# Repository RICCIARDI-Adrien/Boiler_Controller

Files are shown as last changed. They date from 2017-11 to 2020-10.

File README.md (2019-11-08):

# Boiler Controller

## Hardware
Schematics have been drawn using Eagle 8.3.1.  

### Power board
This board contains the AC/DC converter, the relays and the connector to the wall housing.
  
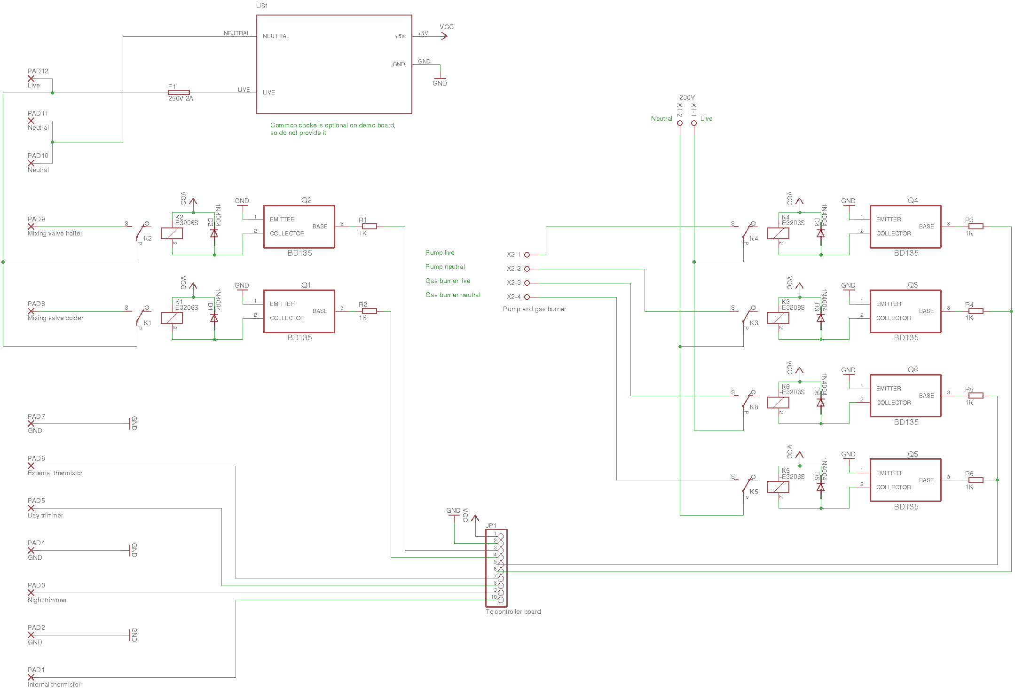
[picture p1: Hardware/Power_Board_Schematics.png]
Power board schematics

  
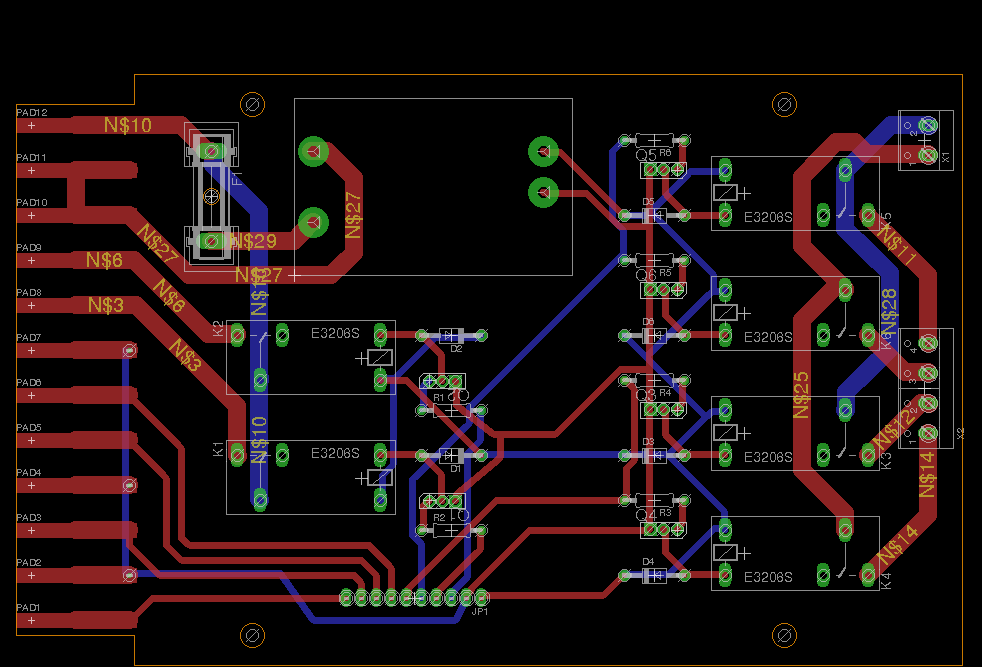
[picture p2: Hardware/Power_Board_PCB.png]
Power board PCB


### Controller board
This board holds the microcontroller and the WiFi to UART bridge.
  
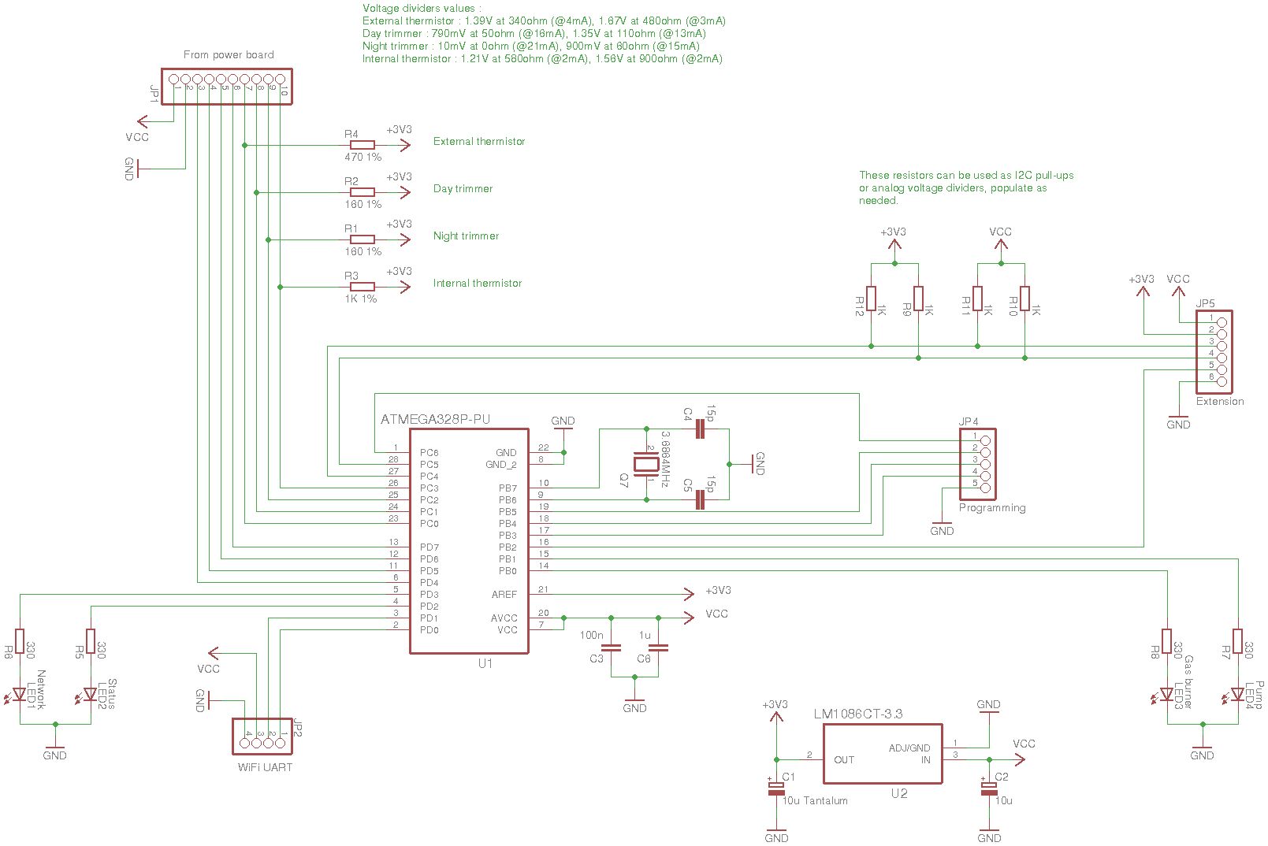
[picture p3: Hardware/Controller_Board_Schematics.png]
Controller board schematics


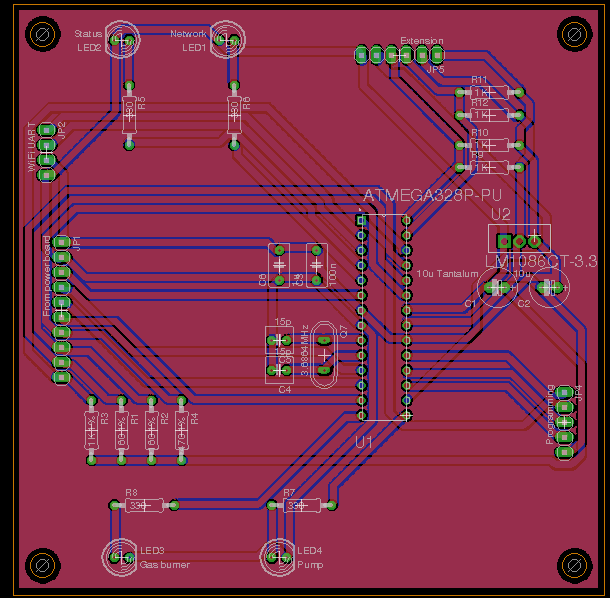
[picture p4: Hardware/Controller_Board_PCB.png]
Controller board PCB


### Components
* [Single pole 16A relay with 5V coil](http://fr.farnell.com/oeg-te-connectivity/omih-ss-105lm-300/relais-spst-no-250vac-30vdc-16a/dp/1891727)
* [BD135 NPN bipolar transistor](http://fr.farnell.com/stmicroelectronics/bd135/transistor-npn-to-126/dp/9801529)
* [1N4007 rectifier diode](http://fr.farnell.com/multicomp/1n4007/diode-1a-1000v/dp/9565051)
* [15pF ceramic capacitor](http://fr.farnell.com/multicomp/mc0805n150j101a2-54mm/condensateur-mlcc-c0g-np0-15pf/dp/2112750)
* [100nF ceramic capacitor](http://fr.farnell.com/multicomp/mc0805b104k500a5-08mm/condensateur-mlcc-0-1uf-50v-x7r/dp/2395773)
* [10uF electrolytic capacitor](http://fr.farnell.com/multicomp/mcgpr16v106m5x11/condensateur-elec-alu-10uf-16v/dp/9451056)
* [10uF tantalum capacitor](http://fr.farnell.com/multicomp/mctar16v106kc/condensateur-tantale-10uf-16v/dp/2395815)
* [5V 2A AC/DC power supply](http://fr.farnell.com/vigortronix/vtx-214-010-205/alimentation-ac-dc-5v-2a/dp/2464685)
* [160ohm 1% resistor](http://fr.farnell.com/multicomp/mf12-160r/resistance-0-125w-1-160r/dp/9342672)
* [330ohm 5% resistor](http://fr.farnell.com/multicomp/mcf-0-25w-330r/resistance-couche-carbon-330r/dp/9339418)
* [470ohm 1% resistor](http://fr.farnell.com/multicomp/mf50-470r/resistance-0-5w-1-470r/dp/9340610)
* [1Kohm 5% resistor](http://fr.farnell.com/multicomp/mcf-0-25w-1k/resistance-couche-carbon-1k-0/dp/9339051)
* [1Kohm 1% resistor](http://fr.farnell.com/multicomp/mf50-1k/resistance-1k-0-5w-1/dp/9339779)
* [Fuseholder](http://fr.farnell.com/littelfuse/64900001039/porte-fusible-cms-20x5mm/dp/1271673)
* [Fuse](http://fr.farnell.com/littelfuse/0232002-mxp/fuse-cartridge-medium-acting-2a/dp/1707348)
* [2-pad terminal](http://fr.farnell.com/camdenboss/ctb0708-2/bornier-standard-2-voies-30-12awg/dp/2315273)
* [4-pad terminal](http://fr.farnell.com/camdenboss/ctb0708-4/bornier-standard-4-voies-30-12awg/dp/2315275)
* [Atmega328p microcontroller](http://fr.farnell.com/microchip/atmega328p-pu/micro-8-bits-avr-32k-flash-28pdip/dp/1715487)
* [3.6864MHz crystal](http://fr.farnell.com/iqd-frequency-products/lfxtal003263/quartz-3-686400mhz/dp/9712909)
* [3.3V LDO](http://fr.farnell.com/texas-instruments/lm1086ct-3-3-nopb/ic-reg-ldo-3-3v-1-5a-to-220/dp/1564628)
* [WiFi to UART bridge](https://www.gotronic.fr/art-module-wifi-uart-grove-113020010-23827.htm)
* [4-pin PCB male connector](https://www.gotronic.fr/art-connecteur-s004-5858.htm)
* [4-pin PCB female connector](https://www.gotronic.fr/art-connecteur-p004-5867.htm)
* [10-pin PCB male connector](https://www.gotronic.fr/art-connecteur-s010-15367.htm)
* [10-pin PCB female connector](https://www.gotronic.fr/art-connecteur-p010-15370.htm)

### Analog signals characteristics
* Day trimmer : resistance variation from 50 to 110ohm.
* Night trimmer : resistance variation from 0 to 60ohm.
* Radiator water start thermistor : resistance variation from 580 (+80°C) to 900ohm (-20°C).
* Outside thermistor : resistance variation from 340 (+40°C) to 480ohm (-10°C).
  
Microcontroller uses a 3.3V precision voltage reference for the ADC module to gain more precision with small variation signals. All voltage dividers must be calculated as the highest variable resistance value results in a 3.3V maximum voltage on the ADC pin.

### Fuse value calculation
AC/DC converter inrush current is 40A for less than 500us, so a temporized fuse is needed to allow the board to boot.  
AC/DC converter maximum input current is 150mA @ 240V, but due to enormous inrush current a big fuse must be used. A 250V/2A fuse has been chosen because this is the fuse used on the VTX-214 demo board (http://www.farnell.com/datasheets/1878969.pdf).

## Software

### Building microcontroller firmware
Install `avr-gcc` to build the microcontroller firmware.
  
Go to `Software/Microcontroller_Firmware` directory and type the following command to build the firmware :
```
make
```
File `Boiler_Controller_Firmware.elf` will be created.

### Flashing microcontroller firmware
You need to install `avrdude` to access to the programmer.  
Firmware can be burnt to the microcontroller memory by connecting an AVR ISP programmer to the controller board ISP connector and typing the command :
```
make flash
```
  
You can override the `PROGRAMMER_SERIAL_PORT` environment variable with the serial port your programmer is connected to.

### Building web server
You need to install `libmicrohttpd` library before building.  
On Debian/Ubuntu system, use the command `sudo apt install libmicrohttpd-dev`.  

To build the web server, go to `Software/Web_Server` directory and type `make`.

### Installing web server
Go to `Software/Web_Server` directory, build web server then type `sudo make install` to install server and init script.  
You can use `sudo make uninstall` command to uninstall the server and all related files.

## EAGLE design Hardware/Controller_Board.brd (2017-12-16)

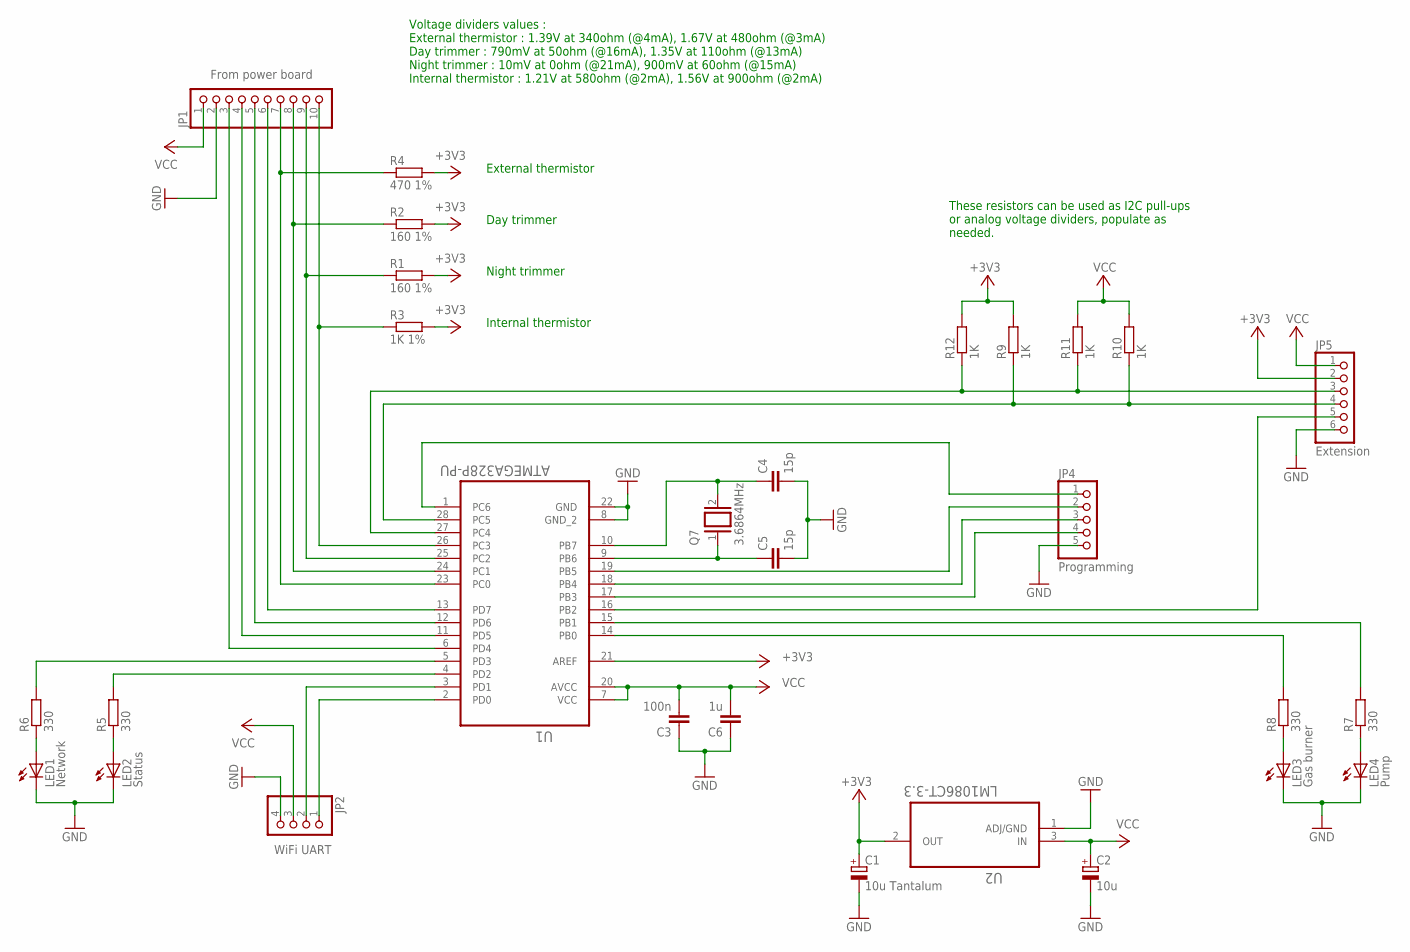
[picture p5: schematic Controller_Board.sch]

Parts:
C1: 10u Tantalum; E2,5-7
C2: 10u; E2,5-7
C3: 100n; C050-035X075
C4, C5: 15p; C025-050X050
C6: 1u; C050-035X075
JP1: From power board; 1X10
JP2: WiFi UART; 1X04
JP4: Programming; 1X05
JP5: Extension; 1X06
LED1: Network; LED5MM
LED2: Status; LED5MM
LED3: Gas burner; LED5MM
LED4: Pump; LED5MM
Q7: 3.6864MHz; QS
R1, R2: 160 1%; 0207/10
R3: 1K 1%; 0207/10
R4: 470 1%; 0207/10
R5, R6, R7, R8: 330; 0207/10
R9, R10, R11, R12: 1K; 0207/10
U1: ATMEGA328P-PU; DIP254P762X457-28
U2: LM1086CT-3.3; TO254P470X1016X2222-3P

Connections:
+3V3: C1.+, JP5.2, R1.2, R2.2, R3.2, R4.2, R9.2, R12.2, U1.21 (AREF), U2.2 (OUT)
GND: C1.-, C2.-, C3.1, C4.2, C5.2, C6.1, JP1.2, JP2.4, JP4.5, JP5.6, LED1.K (C), LED2.K (C), LED3.K (C), LED4.K (C), U1.8 (GND_2), U1.22 (GND), U2.1 (ADJ/GND)
unnamed: JP1.10, R3.1, U1.26 (PC3)
unnamed: JP1.9, R1.1, U1.25 (PC2)
unnamed: JP1.8, R2.1, U1.24 (PC1)
unnamed: JP1.7, R4.1, U1.23 (PC0)
unnamed: JP1.6, U1.13 (PD7)
unnamed: JP1.5, U1.12 (PD6)
unnamed: JP1.4, U1.11 (PD5)
unnamed: JP1.3, U1.6 (PD4)
unnamed: JP2.2, U1.3 (PD1)
unnamed: JP2.1, U1.2 (PD0)
unnamed: LED1.A, R6.1
unnamed: LED2.A, R5.1
unnamed: R6.2, U1.5 (PD3)
unnamed: R5.2, U1.4 (PD2)
unnamed: JP4.2, U1.19 (PB5)
unnamed: JP4.3, U1.18 (PB4)
unnamed: JP4.4, U1.17 (PB3)
unnamed: JP4.1, U1.1 (PC6)
unnamed: JP5.3, R11.1, R12.1, U1.27 (PC4)
unnamed: LED4.A, R7.1
unnamed: LED3.A, R8.1
unnamed: JP5.4, R9.1, R10.1, U1.28 (PC5)
unnamed: R8.2, U1.14 (PB0)
unnamed: R7.2, U1.15 (PB1)
unnamed: JP5.5, U1.16 (PB2)
unnamed: C4.1, Q7.2, U1.10 (PB7)
unnamed: C5.1, Q7.1, U1.9 (PB6)
VCC: C2.+, C3.2, C6.2, JP1.1, JP2.3, JP5.1, R10.2, R11.2, U1.7 (VCC), U1.20 (AVCC), U2.3 (IN)

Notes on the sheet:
Night trimmer
Day trimmer
Internal thermistor
External thermistor
Voltage dividers values : External thermistor : 1.39V at 340ohm (@4mA), 1.67V at 480ohm (@3mA) Day trimmer : 790mV at 50ohm (@16mA), 1.35V at 110ohm (@13mA) Night trimmer : 10mV at 0ohm (@21mA), 900mV at 60ohm (@15mA) Internal thermistor : 1.21V at 580ohm (@2mA), 1.56V at 900ohm (@2mA)
These resistors can be used as I2C pull-ups or analog voltage dividers, populate as needed.

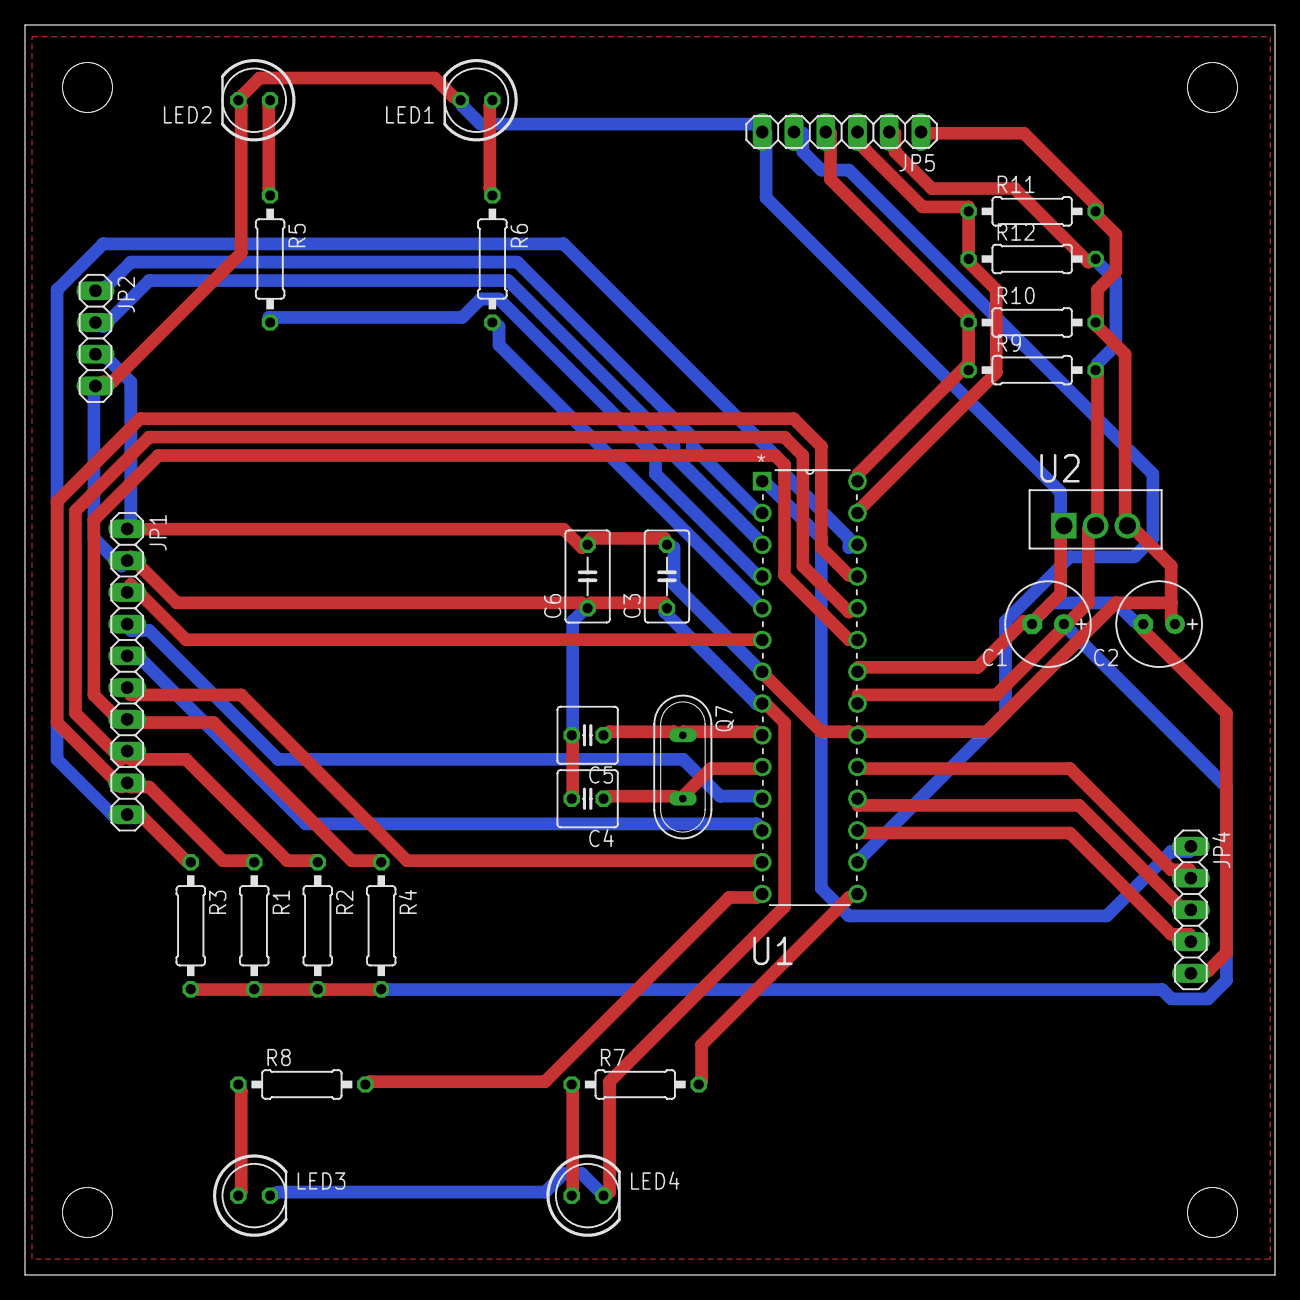
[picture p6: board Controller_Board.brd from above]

Board: 2 copper layers, 100.0 x 100.0 mm, 29 parts (0 on the bottom side), 30 nets.

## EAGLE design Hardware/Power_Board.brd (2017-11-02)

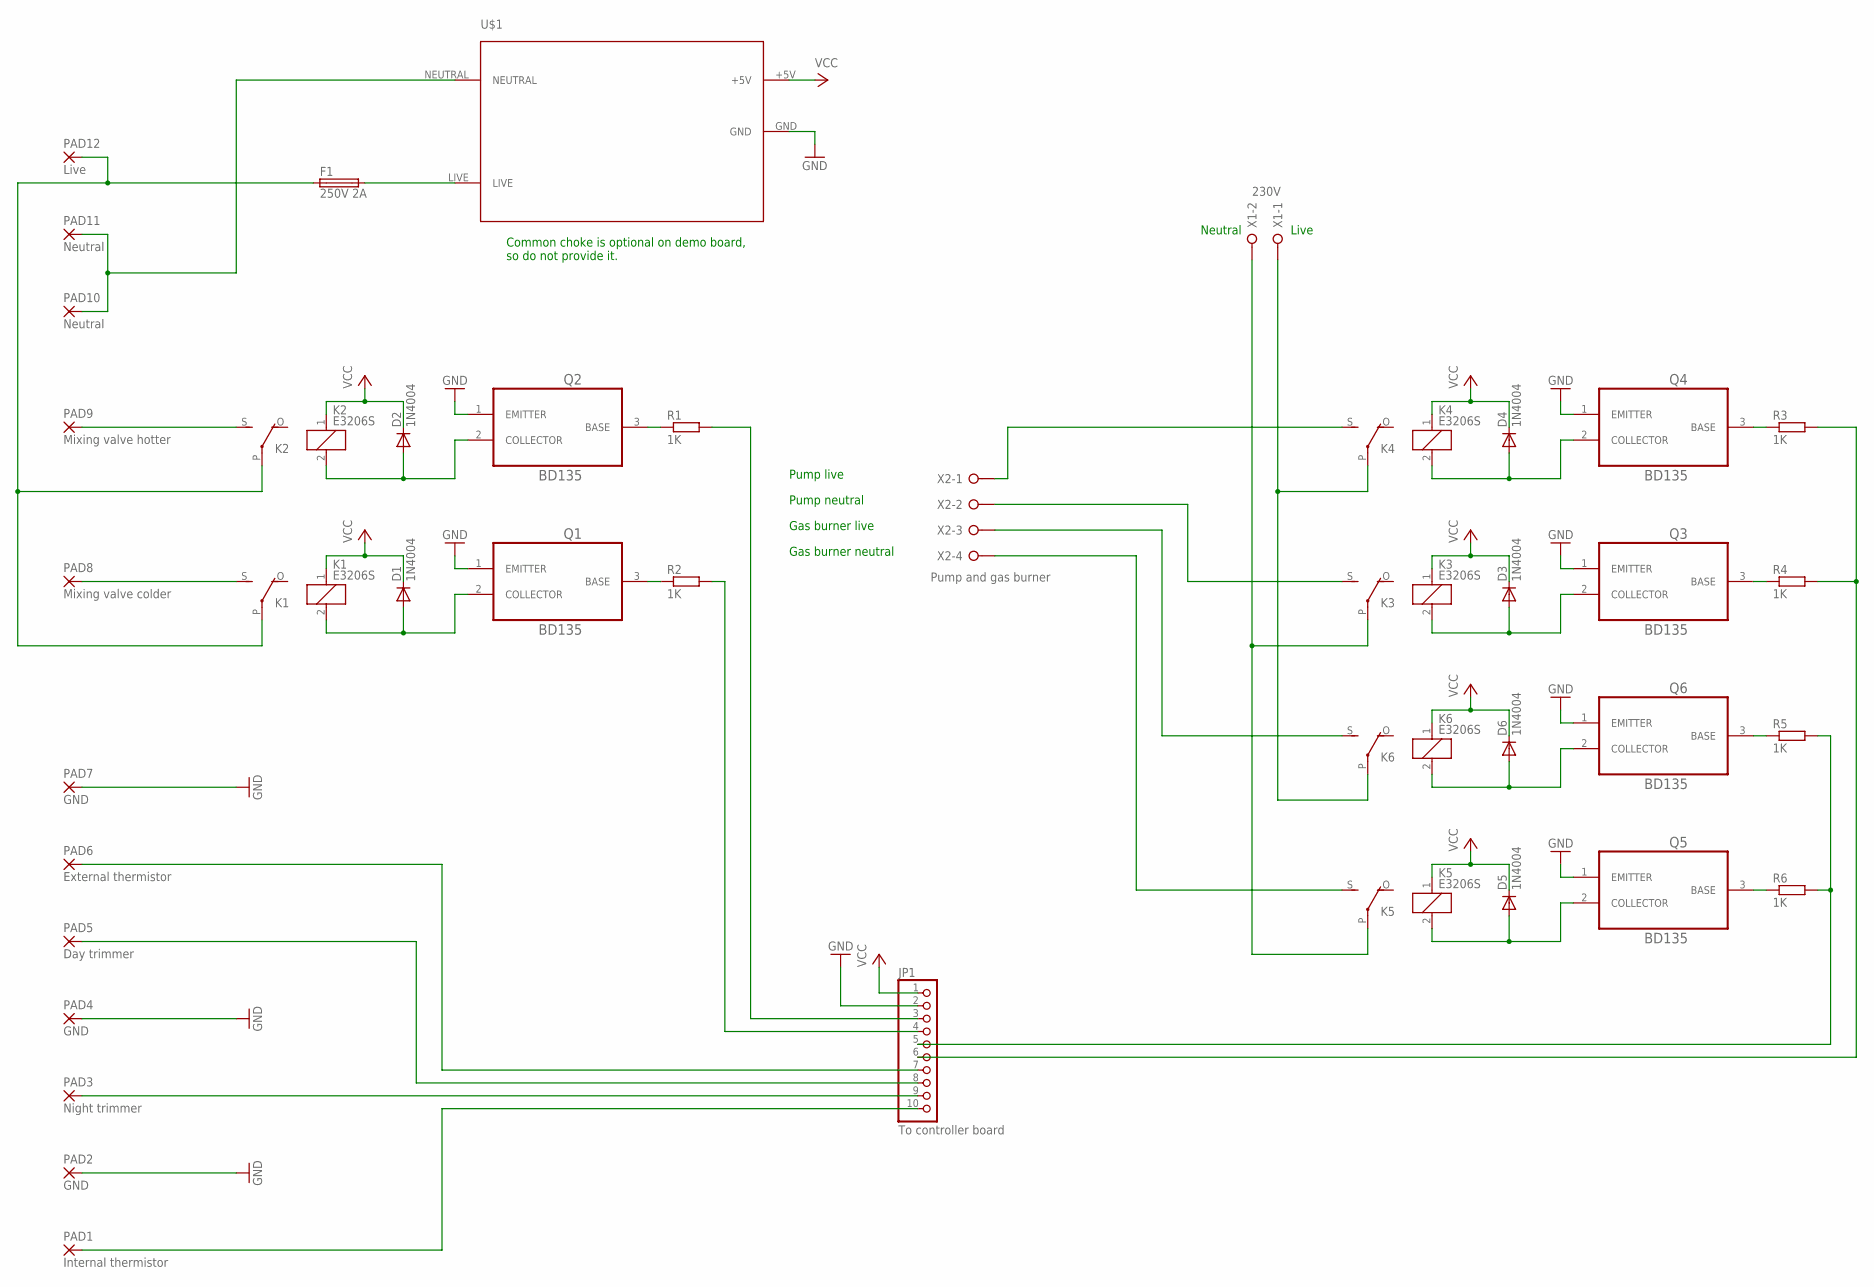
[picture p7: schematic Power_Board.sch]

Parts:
D1, D2, D3, D4, D5, D6: 1N4004; DO41-10
F1: 250V 2A; GSH15
JP1: To controller board; 1X10
K1, K2, K3, K4, K5, K6: E3206S
PAD1: Internal thermistor; SMD2,54-20,32
PAD2, PAD4, PAD7: GND; SMD2,54-20,32
PAD3: Night trimmer; SMD2,54-20,32
PAD5: Day trimmer; SMD2,54-20,32
PAD6: External thermistor; SMD2,54-20,32
PAD8: Mixing valve colder; SMD2,54-20,32
PAD9: Mixing valve hotter; SMD2,54-20,32
PAD10, PAD11: Neutral; SMD2,54-20,32
PAD12: Live; SMD2,54-20,32
Q1, Q2, Q3, Q4, Q5, Q6: BD135; TRANS_BD135
R1, R2, R3, R4, R5, R6: 1K; 0207/10
U$1: VTX-214-010-205
X1: 230V; W237-132
X2: Pump and gas burner; W237-4P

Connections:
GND: JP1.2, PAD2.1, PAD4.1, PAD7.1, Q1.1 (EMITTER), Q2.1 (EMITTER), Q3.1 (EMITTER), Q4.1 (EMITTER), Q5.1 (EMITTER), Q6.1 (EMITTER), U$1.GND
unnamed: JP1.8, PAD5.1
unnamed: JP1.10, PAD1.1
unnamed: K1.S, PAD8.1
unnamed: D1.A, K1.2, Q1.2 (COLLECTOR)
unnamed: Q2.3 (BASE), R1.1
unnamed: K2.S, PAD9.1
unnamed: D2.A, K2.2, Q2.2 (COLLECTOR)
unnamed: JP1.7, PAD6.1
unnamed: JP1.4, R2.2
unnamed: F1.1, K1.P, K2.P, PAD12.1
unnamed: K5.S, X2.4
unnamed: K3.S, X2.2
unnamed: D3.A, K3.2, Q3.2 (COLLECTOR)
unnamed: K4.S, X2.1
unnamed: D4.A, K4.2, Q4.2 (COLLECTOR)
unnamed: Q1.3 (BASE), R2.1
unnamed: D5.A, K5.2, Q5.2 (COLLECTOR)
unnamed: K6.S, X2.3
unnamed: D6.A, K6.2, Q6.2 (COLLECTOR)
unnamed: Q5.3 (BASE), R6.1
unnamed: Q6.3 (BASE), R5.1
unnamed: Q3.3 (BASE), R4.1
unnamed: JP1.5, R5.2, R6.2
unnamed: Q4.3 (BASE), R3.1
unnamed: K4.P, K6.P, X1.1
unnamed: JP1.6, R3.2, R4.2
unnamed: PAD10.1, PAD11.1, U$1.NEUTRAL
unnamed: K3.P, K5.P, X1.2
unnamed: F1.2, U$1.LIVE
unnamed: JP1.3, R1.2
PIN4: JP1.9, PAD3.1
VCC: D1.C, D2.C, D3.C, D4.C, D5.C, D6.C, JP1.1, K1.1, K2.1, K3.1, K4.1, K5.1, K6.1, U$1.+5V

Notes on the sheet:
Pump live
Pump neutral
Gas burner live
Gas burner neutral
Live
Neutral
Common choke is optional on demo board, so do not provide it.

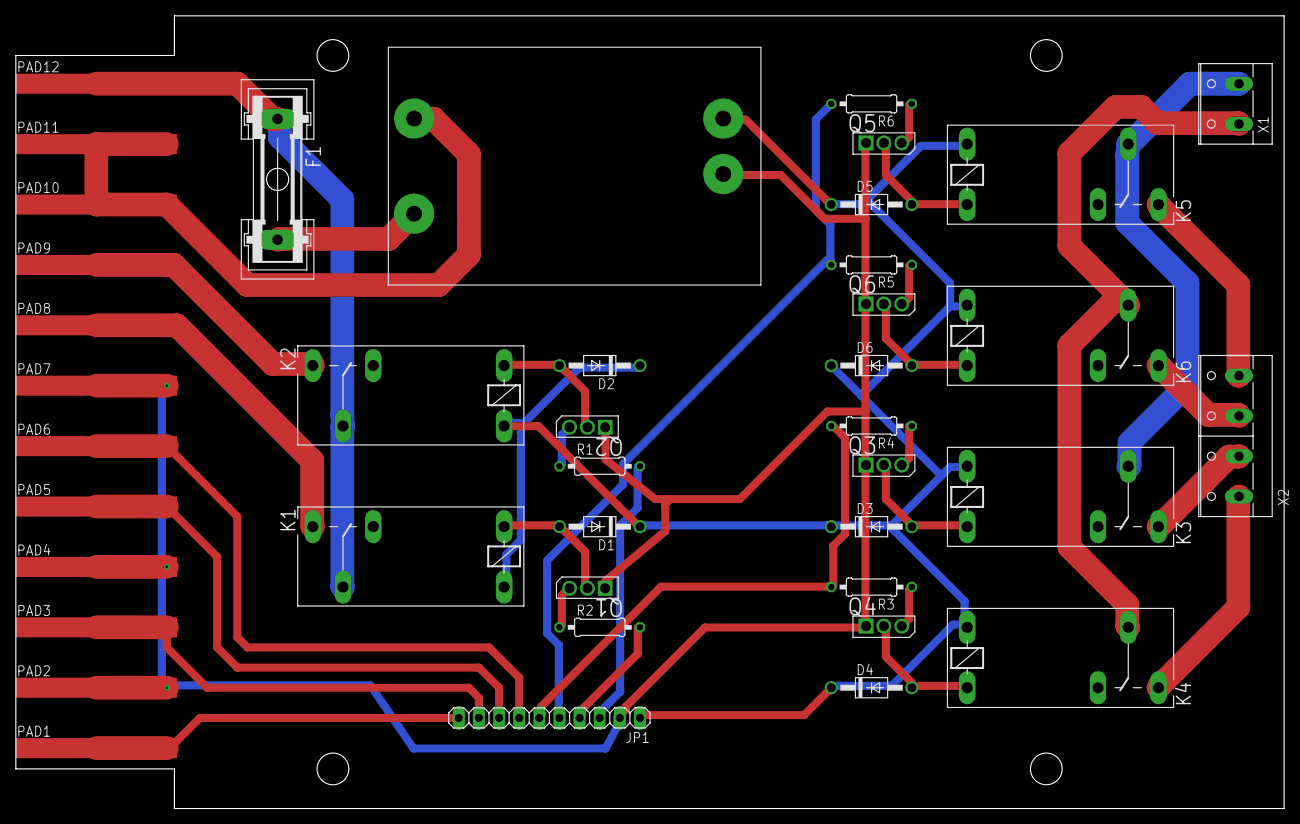
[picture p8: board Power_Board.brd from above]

Board: 2 copper layers, 160.0 x 100.0 mm, 41 parts (0 on the bottom side), 33 nets.

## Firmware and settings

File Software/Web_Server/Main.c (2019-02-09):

/** @file Main.c
 * An HTTP front-end for the boiler controller board.
 * @author Adrien RICCIARDI
 */
#include <microhttpd.h>
#include <stdio.h>
#include <stdlib.h>
#include <string.h>
#include <syslog.h>

//-------------------------------------------------------------------------------------------------
// Private variables
//-------------------------------------------------------------------------------------------------
/** Store the HTML page to send as response. */
static char Main_String_Response[10 * 1024];

//-------------------------------------------------------------------------------------------------
// Private functions
//-------------------------------------------------------------------------------------------------
/** Create the "index.html" page response.
 * @param Pointer_String_Values TODO
 * @return -1 if an error occurred,
 * @return 0 on success.
 */
static int MainPrepareIndexPageResponse(const char *Pointer_String_Values)
{
	sprintf(Main_String_Response,
		"<html>\n"
		"	<head>\n"
		"		<title>Chaudi&egrave;re</title>\n"
		"		<meta charset=\"utf-8\" />\n"
		"	</head>\n"
		"\n"
		"	<body>\n"
		"		<center>\n"
		"		<h1>Chaudi&egrave;re</h1>\n"
		"\n"
		"		<form action=\"index.html\">\n"
		"			<p>\n"
		"				<input type=\"radio\" name=\"power_state\" value=\"1\"> Activ&eacute;e <input type=\"radio\" name=\"power_state\" value=\"0\"> Veille\n"
		"			</p>\n"
		"			<table>\n"
		"			<tr>\n"
		"				<td>Jour</td>\n"
		"				<td><input type=\"range\" min=\"16\" max=\"24\" step=\"1\" name=\"day_temperature\" onchange=\"updateDesiredDayTemperature()\" id=\"id_day_temperature\" value=\"%d\"></td>\n"
		"				<td id=\"id_desired_day_temperature\">%d&deg;C</td>\n"
		"			</tr>\n"
		"			<tr>\n"
		"				<td>Nuit</td>\n"
		"				<td><input type=\"range\" min=\"19\" max=\"27\" step=\"1\" name=\"night_temperature\" onchange=\"updateDesiredNightTemperature()\" id=\"id_night_temperature\" value=\"%d\"></td>\n"
		"				<td id=\"id_desired_night_temperature\">%d&deg;C</td>\n"
		"			</tr>\n"
		"			</table>\n"
		"\n"
		"			<p>\n"
		"				<input type=\"submit\" value=\"Valider\" />\n"
		"			</p>\n"
		"		</form>\n"
		"		</center>\n"
		"\n"
		"		<script>\n"
		"			function updateDesiredDayTemperature()\n"
		"			{\n"
		"				var temperature = document.getElementById(\"id_day_temperature\").value;\n"
		"				temperature = temperature.concat(\"&deg;C\");\n"
		"				document.getElementById(\"id_desired_day_temperature\").innerHTML = temperature;\n"
		"			}\n"
		"\n"
		"			function updateDesiredNightTemperature()\n"
		"			{\n"
		"				var temperature = document.getElementById(\"id_night_temperature\").value;\n"
		"				temperature = temperature.concat(\"&deg;C\");\n"
		"				document.getElementById(\"id_desired_night_temperature\").innerHTML = temperature;\n"
		"			}\n"
		"		</script>\n"
		"	</body>\n"
		"</html>\n", 23, 23, 27, 27);
	
	return 0;
}

/** Called when a client requests a web page.
 * @param Pointer_Custom_Data Custom data provided to MHD_start_daemon().
 * @param Pointer_Connection The connection handle used to build the response.
 * @param Pointer_String_URL The URL requested by the client.
 * @param Pointer_String_Method The HTTP method (GET, POST...) used to send the query.
 * @param Pointer_String_Version HTTP protocol version.
 * @param Pointer_String_Upload_Data The data to upload to POST request.
 * @param Pointer_Upload_Data_Size How many bytes of data to upload to a POST request.
 * @param Pointer_Persistent_Connection_Custom_Data A custom data pointer that won't change across callback calls (for the same connection).
 * @return MHD_NO to close the connection,
 * @return MHD_YES to continue servicing the client request.
 */
static int MainWebServerAccessHandlerCallback(void __attribute__((unused)) *Pointer_Custom_Data, struct MHD_Connection *Pointer_Connection, const char *Pointer_String_URL, const char *Pointer_String_Method, const char __attribute__((unused)) *Pointer_String_Version, const char __attribute__((unused)) *Pointer_String_Upload_Data, size_t __attribute__((unused)) *Pointer_Upload_Data_Size, void __attribute__((unused)) **Pointer_Persistent_Connection_Custom_Data)
{
	struct MHD_Response *Pointer_Response;
	int Return_Value;
	
	printf("Pointer_String_URL=%s Pointer_Persistent_Connection_Custom_Data=%p\n", Pointer_String_URL, *Pointer_Persistent_Connection_Custom_Data);
	
	// Handle only GET methods
	if (strcmp(Pointer_String_Method, "GET") != 0) return MHD_NO;
	
	// Callback is called when a new connection header is received, and no response must be sent at this time
	if (*Pointer_Persistent_Connection_Custom_Data == NULL) // This value is always NULL for a new connection
	{
		*Pointer_Persistent_Connection_Custom_Data = (void *) 1; // Set the value to something else to tell that connection first step has been processed
		return MHD_YES; // Continue servicing request
	}
	
	// Create the page to send as the response
	if ((strncmp(Pointer_String_URL, "/", 1) == 0) || (strncmp(Pointer_String_URL, "/index.html", 11)))
	{
		if (MainPrepareIndexPageResponse(Pointer_String_URL) != 0) return MHD_NO;
	}
	else return MHD_NO;
	
	// Create the response to send
	Pointer_Response = MHD_create_response_from_buffer(strlen(Main_String_Response), Main_String_Response, MHD_RESPMEM_PERSISTENT);
	if (Pointer_Response == NULL) return MHD_NO;
	
	// Send the response
	Return_Value = MHD_queue_response(Pointer_Connection, MHD_HTTP_OK, Pointer_Response);
	MHD_destroy_response(Pointer_Response);
	
	return Return_Value;
}

//-------------------------------------------------------------------------------------------------
// Entry point
//-------------------------------------------------------------------------------------------------
int main(int argc, char *argv[])
{
	unsigned short Web_Server_Port;
	struct MHD_Daemon *Pointer_Web_Server;
	
	// Start logging system
	openlog(argv[0], 0, LOG_DAEMON);
	
	// Check parameters
	if (argc != 2)
	{
		syslog(LOG_ERR, "Bad parameters. Usage : %s Server_Port", argv[0]);
		printf("Bad parameters. Usage : %s Server_Port\n", argv[0]);
		return EXIT_FAILURE;
	}
	Web_Server_Port = atoi(argv[1]);
	
	// Start web server
	Pointer_Web_Server = MHD_start_daemon(MHD_USE_THREAD_PER_CONNECTION, Web_Server_Port, NULL, NULL, MainWebServerAccessHandlerCallback, NULL, MHD_OPTION_END);
	if (Pointer_Web_Server == NULL)
	{
		syslog(LOG_ERR, "Failed to start web server daemon, exiting.\n");
		return EXIT_FAILURE;
	}
	
	while (1);
	
	return 0;
}

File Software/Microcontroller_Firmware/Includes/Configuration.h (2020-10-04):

/** @file Configuration.h
 * Gather all program configurable parameters.
 * @author Adrien RICCIARDI
 */
#ifndef H_CONFIGURATION_H
#define H_CONFIGURATION_H

//-------------------------------------------------------------------------------------------------
// Constants
//-------------------------------------------------------------------------------------------------
/** The access point to connect to SSID. */
#define CONFIGURATION_PROTOCOL_WIFI_ACCESS_POINT_SSID "test"
/** The access point to connect to password. */
#define CONFIGURATION_PROTOCOL_WIFI_ACCESS_POINT_PASSWORD "password"

/** The server to connect to IP address. */
#define CONFIGURATION_PROTOCOL_WIFI_SERVER_ADDRESS "192.168.1.100"
/** The server to connect to port. */
#define CONFIGURATION_PROTOCOL_WIFI_SERVER_PORT "1234"

/** The current firmware version. */
#define CONFIGURATION_FIRMWARE_VERSION 2

/** Mixing valve time in seconds to go from one side to the other side. */
#define CONFIGURATION_MIXING_VALVE_MAXIMUM_MOVING_TIME (20 * 60) // Valve needs about 18 minutes to travel from one side to the other, set 20 minutes to get some margin (valve has internal limit switches)

/** The reference temperature (in °C) the trimmers use when they are set to 0. */
#define CONFIGURATION_TRIMMERS_REFERENCE_TEMPERATURE 20

/** Minimum temperature value (clamped after heating curve computation). */
#define CONFIGURATION_HEATING_CURVE_MINIMUM_TEMPERATURE 10 // TODO determine a good value
/** Maximum temperature value (clamped after heating curve computation). */
#define CONFIGURATION_HEATING_CURVE_MAXIMUM_TEMPERATURE 70 // TODO determine a good value

/** Add this amount of degrees to the gas burner temperature to reach to avoid turning the gas burner off too often. */
#define CONFIGURATION_GAS_BURNER_TEMPERATURE_HYSTERESIS_HIGH 5
/** Subtract this amount of degrees to the gas burner temperature to reach to avoid turning the gas burner on too often. */
#define CONFIGURATION_GAS_BURNER_TEMPERATURE_HYSTERESIS_LOW 8

/** How many ADC samples to use to compute the moving average value. */
#define CONFIGURATION_ADC_MOVING_AVERAGE_SAMPLES_COUNT 5

/** Heating curve coefficient least significant byte address in internal EEPROM. */
#define CONFIGURATION_EEPROM_ADDRESS_HEATING_CURVE_COEFFICIENT_LOW_BYTE 0
/** Heating curve coefficient most significant byte address in internal EEPROM. */
#define CONFIGURATION_EEPROM_ADDRESS_HEATING_CURVE_COEFFICIENT_HIGH_BYTE 1
/** Heating curve parallel shift least significant byte address in internal EEPROM. */
#define CONFIGURATION_EEPROM_ADDRESS_HEATING_CURVE_PARALLEL_SHIFT_LOW_BYTE 2
/** Heating curve parallel shift most significant byte address in internal EEPROM. */
#define CONFIGURATION_EEPROM_ADDRESS_HEATING_CURVE_PARALLEL_SHIFT_HIGH_BYTE 3

#endif

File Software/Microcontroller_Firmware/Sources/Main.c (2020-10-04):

/** @file Main.c
 * Boiler controller entry point and main loop.
 * @author Adrien RICCIARDI
 */
#include <ADC.h>
#include <avr/interrupt.h>
#include <avr/io.h>
#include <Configuration.h>
#include <Led.h>
#include <Mixing_Valve.h>
#include <Protocol.h>
#include <Relay.h>
#include <Temperature.h>
#include <util/delay.h>

//-------------------------------------------------------------------------------------------------
// Private variables
//-------------------------------------------------------------------------------------------------
/** Configure microcontroller fuses. */
FUSES =
{
	FUSE_CKSEL3, // Fuses low byte : use the longest power-on delay to make sure power supply voltage is stabilized when core starts, select a full swing crystal oscillator with brown-out detection enabled
	FUSE_SPIEN & FUSE_EESAVE, // Fuses high byte : enable Serial programming and Data Downloading, keep EEPROM content when erasing the chip, give less room possible to the bootloader (for now)
	FUSE_BODLEVEL2 // Fuses extended byte : set brown-out reset voltage to approximately 4.3V
};

//-------------------------------------------------------------------------------------------------
// Entry point
//-------------------------------------------------------------------------------------------------
int main(void) // Can't use void return type because it triggers a warning
{
	unsigned char Is_WiFi_Successfully_Initialized, Is_Status_Led_On = 1, Is_Boiler_Running_Before = 0, Is_Boiler_Running_Now; // Consider boiler as stopped on boot
	signed char Radiator_Water_Start_Temperature, Target_Start_Water_Temperature;
	
	// Initialize modules
	LedInitialize();
	LedTurnOn(LED_ID_STATUS); // Turn status led on to tell controller is booting
	ADCInitialize();
	RelayInitialize();
	TemperatureInitialize();
	Is_WiFi_Successfully_Initialized = ProtocolInitialize();
	
	// Enable interrupts now that all modules have been configured
	sei();
	
	// Tell whether network is working
	if (!Is_WiFi_Successfully_Initialized) LedTurnOn(LED_ID_NETWORK_ERROR);
	
	while (1)
	{
		// Sample all analog values
		ADCTask();
		
		// Compute target temperature to reach (compute it even when boiler is not running in order to report a good value through protocol commands)
		TemperatureTask();
		
		// Cache current running state as it is used several times
		Is_Boiler_Running_Now = ProtocolIsBoilerRunning();
		
		// Handle gas burner
		if (Is_Boiler_Running_Now)
		{
			// Cache converted temperature values (conversion computations cost a lot of cycles)
			Radiator_Water_Start_Temperature = TemperatureGetSensorValue(TEMPERATURE_SENSOR_ID_RADIATOR_START);
			Target_Start_Water_Temperature = TemperatureGetTargetStartWaterTemperature();
			
			// Gas burner control
			if (Radiator_Water_Start_Temperature <= Target_Start_Water_Temperature - CONFIGURATION_GAS_BURNER_TEMPERATURE_HYSTERESIS_LOW) RelayTurnOn(RELAY_ID_GAS_BURNER);
			else if (Radiator_Water_Start_Temperature >= Target_Start_Water_Temperature + CONFIGURATION_GAS_BURNER_TEMPERATURE_HYSTERESIS_HIGH) RelayTurnOff(RELAY_ID_GAS_BURNER);
		}
		
		// Execute the following actions only once when running state changes
		if (Is_Boiler_Running_Now != Is_Boiler_Running_Before)
		{
			if (Is_Boiler_Running_Now)
			{
				// Start pump
				RelayTurnOn(RELAY_ID_PUMP);
				
				// Progressively send water to the radiators (assume valve is on the left position, which is set when boiler is stopped)
				MixingValveSetPosition(MIXING_VALVE_POSITION_RIGHT);
				
				// Tell user boiler is running
				LedTurnOff(LED_ID_BOILER_RUNNING_MODE);
			}
			else
			{
				// Make sure burner is stopped
				RelayTurnOff(RELAY_ID_GAS_BURNER);
				
				// Stop pump
				RelayTurnOff(RELAY_ID_PUMP);
				
				// Close radiators water circuit to send cold water only to the gas burner on next run
				MixingValveSetPosition(MIXING_VALVE_POSITION_LEFT);
				
				// Tell user boiler is idle
				LedTurnOn(LED_ID_BOILER_RUNNING_MODE);
			}
		}
		Is_Boiler_Running_Before = Is_Boiler_Running_Now;
		
		// Make the mixing valve moves
		MixingValveTask();
		
		// Tell that controller is still alive
		if (Is_Status_Led_On)
		{
			LedTurnOn(LED_ID_STATUS);
			Is_Status_Led_On = 0;
		}
		else
		{
			LedTurnOff(LED_ID_STATUS);
			Is_Status_Led_On = 1;
		}
		
		// This is a slow regulation process, we can safely wait some time between each loop
		_delay_ms(1000);
	}
}

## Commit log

2017-07-05 Initial commit. Added schematics analog sampling part.
    [Mother_Board.sch]
2017-07-05 Renamed schematics file for more coherency.
    [Main_Board.sch]
2017-07-05 Used more generic resistors in the voltage dividers.
    [Main_Board.sch]
2017-07-06 Added relay blocks to the schematics.
    [Main_Board.sch]
2017-07-08 Used an ATMEGA328 microcontroller to sample analog signals and to control the relays.
    [Main_Board.sch]
2017-07-08 Replaced +5V supply signal by Vcc for more coherency.
    [Main_Board.sch]
2017-07-08 Fixed reference voltage input pin capacitor value.
    [Main_Board.sch]
2017-07-10 Splitted circuit in two PCBs to ease routing.
    [Controller_Board.sch, Power_Board.sch]
2017-07-10 Decreased a bit the controller board schematics height.
    [Controller_Board.sch]
2017-07-14 Added a status led on the controller board.
    [Controller_Board.sch]
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2017-08-06 Started microcontroller protocol module implementation. Non-interrupt UART driver part is working.
    [Configuration.h]
2017-08-06 Configured ESP8266 UART to WiFi module to act as a transparent brigde.
    [Configuration.h]
2017-08-24 Added protocol reception and transmission state machines to microcontroller firmware, also implemented 'get firmware version' command.
    [Configuration.h]
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2017-09-02 Increased AC/DC package pads diameter and drill diameter to make sure the component will fit.
2017-09-03 Updated schematic files to Eagle 8.3.1 and added the AC/DC converter to the power board.
    [Controller_Board.sch, Power_Board.sch]
2017-09-10 Added a 2-pad terminal to supply the pump and the gas burner from a different 230V source than the one provided by the wall housing, which might not be powerful enough.
    [Power_Board.sch]
2017-09-11 Added power board PCB.
    [Power_Board.brd, Power_Board.sch]
2017-11-01 Added a fuse to the power board and made PCB routes thicker.
    [Main_Board.brd, Power_Board.brd, Power_Board.sch]
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2017-11-01 Added holes to the power board PCB to attach the controller board PCB to.
    [Power_Board.brd]
2017-11-02 Added bigger pads to the power board PCB, so the PCB coating won't recover the pads.
    [Power_Board.brd, Power_Board.sch]
2017-11-19 Removed old main board file (useless now because the initial board has been splitted in two separate boards.
    [Main_Board.brd]
2017-11-19 Added one more decoupling capacitor close to the control board microcontroller, changed 15pF capacitors package to the good one, added a second led just in case.
    [Controller_Board.sch]
2017-11-20 Added spare leds and connector to the controller board. Components could be populated if needed.
    [Controller_Board.sch]
2017-11-20 Added controller board PCB.
    [Controller_Board.brd]
2017-11-25 Added microcontroller SPI programming header to the controller board.
    [Controller_Board.brd, Controller_Board.sch]
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2017-11-25 Automatically reset the ESP8266 module on microcontroller boot to avoid powering off then powering on the whole board after programming the microcontroller.
    [Protocol.c]
2017-12-03 Started bootloader implementation. For now bootloader makes a led blink then jumps to application area.
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2017-12-03 Configured maximum oscillator startup time to ensure it is stable when UART is used.
    [Main.c]
2017-12-03 Added fuses flashing from firmware (this will be removed when bootloader will be working).
2017-12-03 Added WiFi connection failure detection to firmware.
    [Main.c, Protocol.c]
2017-12-03 Added a led module to the firmware to easily handle the multiple controller board leds.
2017-12-05 Changed controller board voltage dividers resistor values to allow a precision 3.3V reference voltage to be used. AC/DC 5V output voltage is not stable enough to grant precise measures.
    [Controller_Board.sch]
2017-12-05 Updated controller board PCB with new LDO reference voltage.
    [Controller_Board.brd]
2017-12-15 Added a ground plane to the controller board to increase the copper plating index.
    [Controller_Board.brd]
2017-12-16 Added +3.3V and a GPIO to the controller board extension connector.
    [Controller_Board.brd, Controller_Board.sch]
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2017-12-17 Added external and start thermistors temperature conversion utility and the related protocol commands.
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2017-12-17 Gave more coherent names to thermistors and temperatures in the microcontroller firmware.
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2018-01-02 Added 'set mixing valve maximum moving time' command to microcontroller firmware.
    [Configuration.h]
2018-01-07 Made a difference between sensor temperatures and other temperatures (like trimmers ones or the room desired temperature) for more coherency.
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2018-01-07 Added a function to determine currently desired room temperature according to trimmers position, time of the day and protocol ability to set desired temperature.
    [Configuration.h]
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2018-01-07 Added heating curve computation.
    [Configuration.h]
2018-01-07 Added gas burner control to microcontroller firmware.
    [Configuration.h]
2018-01-07 Made cached temperature variables local in microcontroller firmware main() function because these variables are not shared with Main module private functions.
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2018-01-13 Swapped pump and gas burner relays to be conform to board final connection.
    [Relay.h]
2018-01-14 Set real mixing valve maximum moving time.
    [Configuration.h]
2018-01-14 Taken into account boiler 'running' and 'idle' states. Adapted mixing valve behavior to these new states.
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2018-02-04 Added a moving average computation on each sampled ADC channel to filter signal spikes.
    [Configuration.h]
2018-02-04 Added separated high and low values for the gas burner hysteresis.
    [Configuration.h]
2018-02-04 Fixed protocol command payload reception in microcontroller firmware.
    [Protocol.c]
2018-02-04 Made sure gas burner is stopped when boiler running mode is set to off.
    [Main.c]
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2018-04-16 Fixed a bug in the microcontroller 'set heating curve parameters' protocol command (expected payload was not defined).
    [Protocol.c]
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2019-02-09 Improved microcontroller firmware 'get desired room temperature' and 'set desired room temperature' to be able to get and set night and day temperatures separately.
    [Configuration.h]
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2019-02-12 Added final server IP address to microcontroller firmware configuration to avoid setting it each time.
    [Configuration.h]
2019-02-12 Fixed memory leaks in web server 'index' page arguments parsing; fixed sending uninitialized argument values to board.
    [Main.c]
2019-02-12 Removed useless fix that tried to free a static string in the web server.
    [Main.c]
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2019-11-08 Added heating curve parameters loading from and storing to internal EEPROM to microcontroller firmware.
    [Configuration.h]
2019-11-08 Moved web server index page generation to a dedicated file.
    [Configuration.h]
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2020-10-04 Enabled keep alive on TCP connection between board and server to avoid board disconnecting and reconnecting when server is not active.
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2020-10-04 Prevented user from setting an empty heating curve in web server settings page.
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2020-10-04 Bumped microcontroller firmware to version 2.
    [Configuration.h]
